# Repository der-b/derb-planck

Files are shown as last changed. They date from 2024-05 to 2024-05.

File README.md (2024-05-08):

# derb-planck

DIY mechanical keyboard which can be connected to several hosts at the same time.
[See blog post for more details.](https://der-b.com/posts/2024-05-08-mechanical-keyboard-derb-planck/)

## PCB

The PCB is designed with KiCad and is located in the subdirectory "PCB".

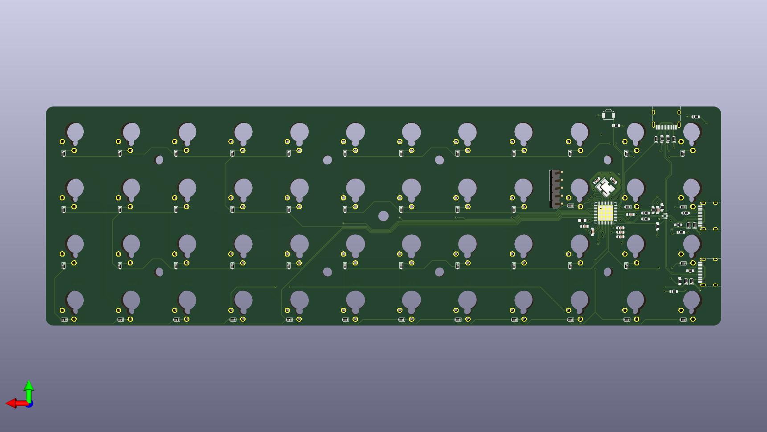
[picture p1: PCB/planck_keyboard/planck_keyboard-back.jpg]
Back

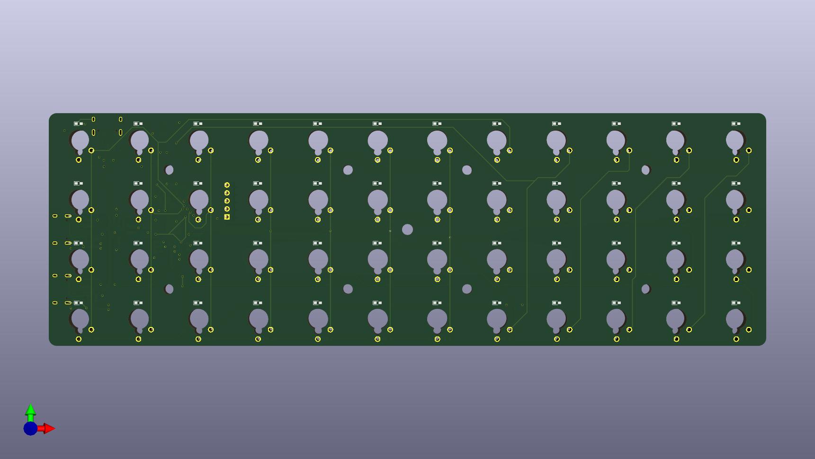
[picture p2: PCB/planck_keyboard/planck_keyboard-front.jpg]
Front


## Case

The Case is designed with FreeCAD and is located in the subdirectory "case".

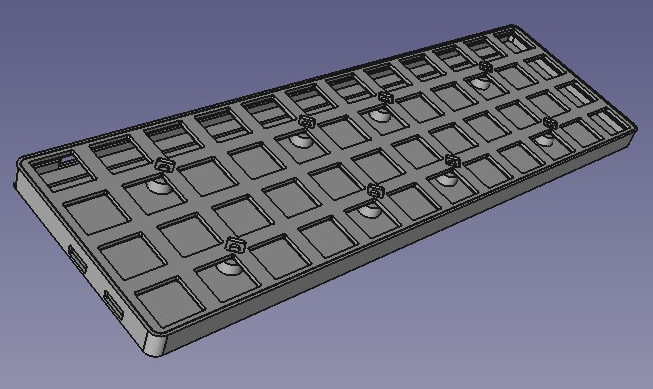
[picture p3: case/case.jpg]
Case


## Firmeware

[This keyboard uses QMK as firmware.](https://github.com/der-b/qmk_firmware/tree/derb_planck/keyboards/handwired/derb_planck)

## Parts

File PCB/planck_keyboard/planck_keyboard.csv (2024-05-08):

# | Reference | Qty | Value | Footprint | DNP
1 | C1, C2, C3, C4 | 4 | 0.1u | Capacitor_SMD:C_0603_1608Metric_Pad1.08x0.95mm_HandSolder
2 | C5 | 1 | 4.7u | Capacitor_SMD:C_0603_1608Metric_Pad1.08x0.95mm_HandSolder
3 | C6 | 1 | 1000p | Capacitor_SMD:C_0603_1608Metric_Pad1.08x0.95mm_HandSolder
4 | C7, C8 | 2 | 22p | Capacitor_SMD:C_0603_1608Metric_Pad1.08x0.95mm_HandSolder
5 | C9 | 1 | 1u | Capacitor_SMD:C_0603_1608Metric_Pad1.08x0.95mm_HandSolder
6 | D0, D1, D2, D3, D4, D5, D6, D7, D8, D9, D10, D11, D12, D13, D14, D15, D16, D17, D18, D19, D20, D21, D22, D23, D24, D25, D26, D27, D28, D29, D30, D31, D32, D33, D34, D35, D36, D37, D38, D39, D40, D41, D42, D43, D44, D45, D46, D47, D48, D49, D50, D51, D52, D53 | 54 | D | Diode_SMD:D_SOD-523
7 | H1, H2, H3, H4, H5, H6, H7, H8 | 8 | MountingHole | MountingHole:MountingHole_3.2mm_M3
8 | HTP0 | 1 | MountingHole | MountingHole:MountingHole_3.5mm
9 | J1, J2, J3 | 3 | USB_C_Receptacle_USB2.0 | Connector_USB:USB_C_Receptacle_HRO_TYPE-C-31-M-12
10 | J4 | 1 | Conn_01x05 | Connector_PinHeader_2.54mm:PinHeader_1x05_P2.54mm_Vertical
11 | R1 | 1 | 100 | Resistor_SMD:R_0603_1608Metric_Pad0.98x0.95mm_HandSolder
12 | R2, R3 | 2 | 22 | Resistor_SMD:R_0603_1608Metric_Pad0.98x0.95mm_HandSolder
13 | R4, R5, R6, R7 | 4 | 10k | Resistor_SMD:R_0603_1608Metric_Pad0.98x0.95mm_HandSolder
14 | R8, R9, R10, R11, R12, R13 | 6 | 5k1 | Resistor_SMD:R_0603_1608Metric_Pad0.98x0.95mm_HandSolder
15 | R14, R15, R16 | 3 | 1k | Resistor_SMD:R_0603_1608Metric_Pad0.98x0.95mm_HandSolder
16 | SW0, SW1, SW2, SW3, SW4, SW5, SW6, SW7, SW8, SW9, SW10, SW11, SW12, SW13, SW14, SW15, SW16, SW17, SW18, SW19, SW20, SW21, SW22, SW23, SW24, SW25, SW26, SW27, SW28, SW29, SW30, SW31, SW32, SW33, SW34, SW35, SW36, SW37, SW38, SW39, SW40, SW41, SW42, SW43, SW44, SW45, SW46, SW47 | 48 | SW_SPST_LED | planck_keyboard:SW_Cherry_MX_LowProfile_1.00u_PCB_V2
17 | SW_RESET1 | 1 | SW_Push | Button_Switch_SMD:SW_SPST_B3U-3000P
18 | U1 | 1 | ATmega32U4RC-M | Package_DFN_QFN:QFN-44-1EP_7x7mm_P0.5mm_EP5.2x5.2mm
19 | U2 | 1 | FSUSB63 | planck_keyboard:FSUSB63
20 | Y1 | 1 | ECS-160-9-33B-CKM-TR3 | Crystal:Crystal_SMD_3225-4Pin_3.2x2.5mm_HandSoldering

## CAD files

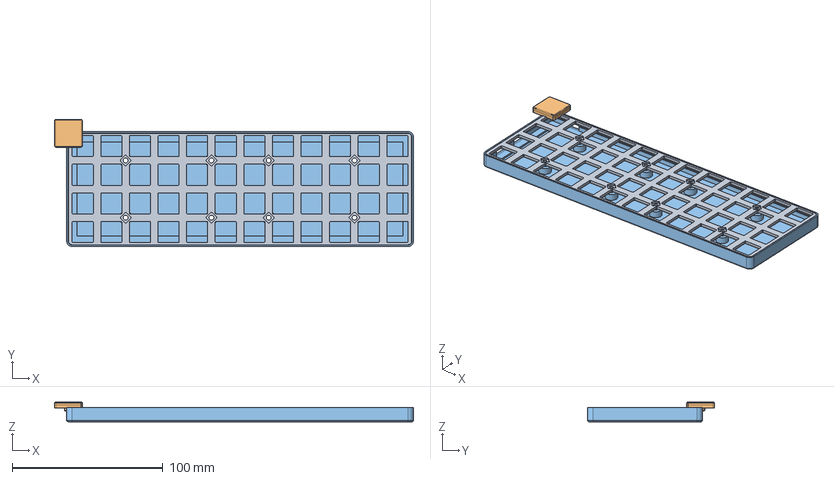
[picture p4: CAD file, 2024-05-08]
case/Case.FCStd
238.5 x 84.5 x 13.0 mm
FacePlate
KeyCap
Case

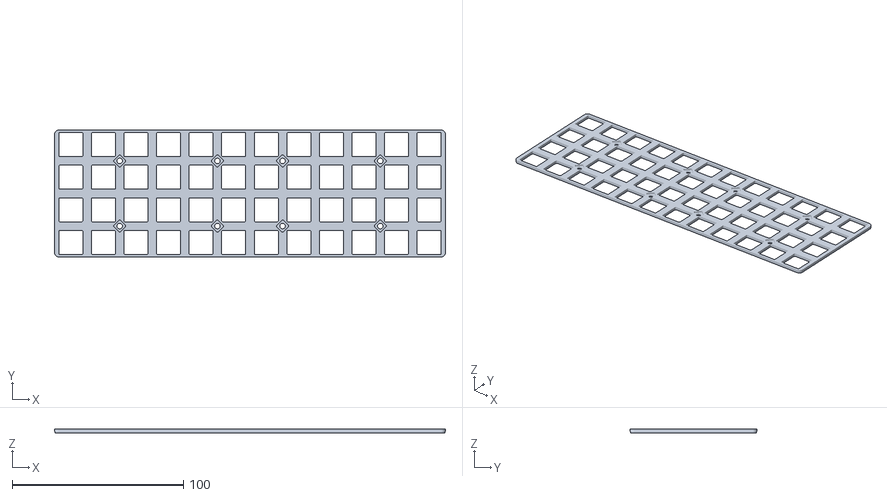
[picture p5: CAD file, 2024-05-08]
case/FacePlate.stl
228.0 x 74.0 x 2.20

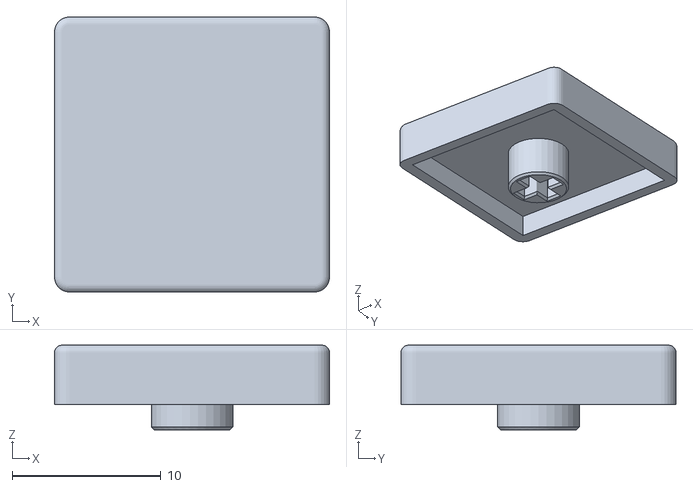
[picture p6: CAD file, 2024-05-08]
case/KeyCap.stl
18.5 x 18.5 x 5.70

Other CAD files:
case/Case.stl

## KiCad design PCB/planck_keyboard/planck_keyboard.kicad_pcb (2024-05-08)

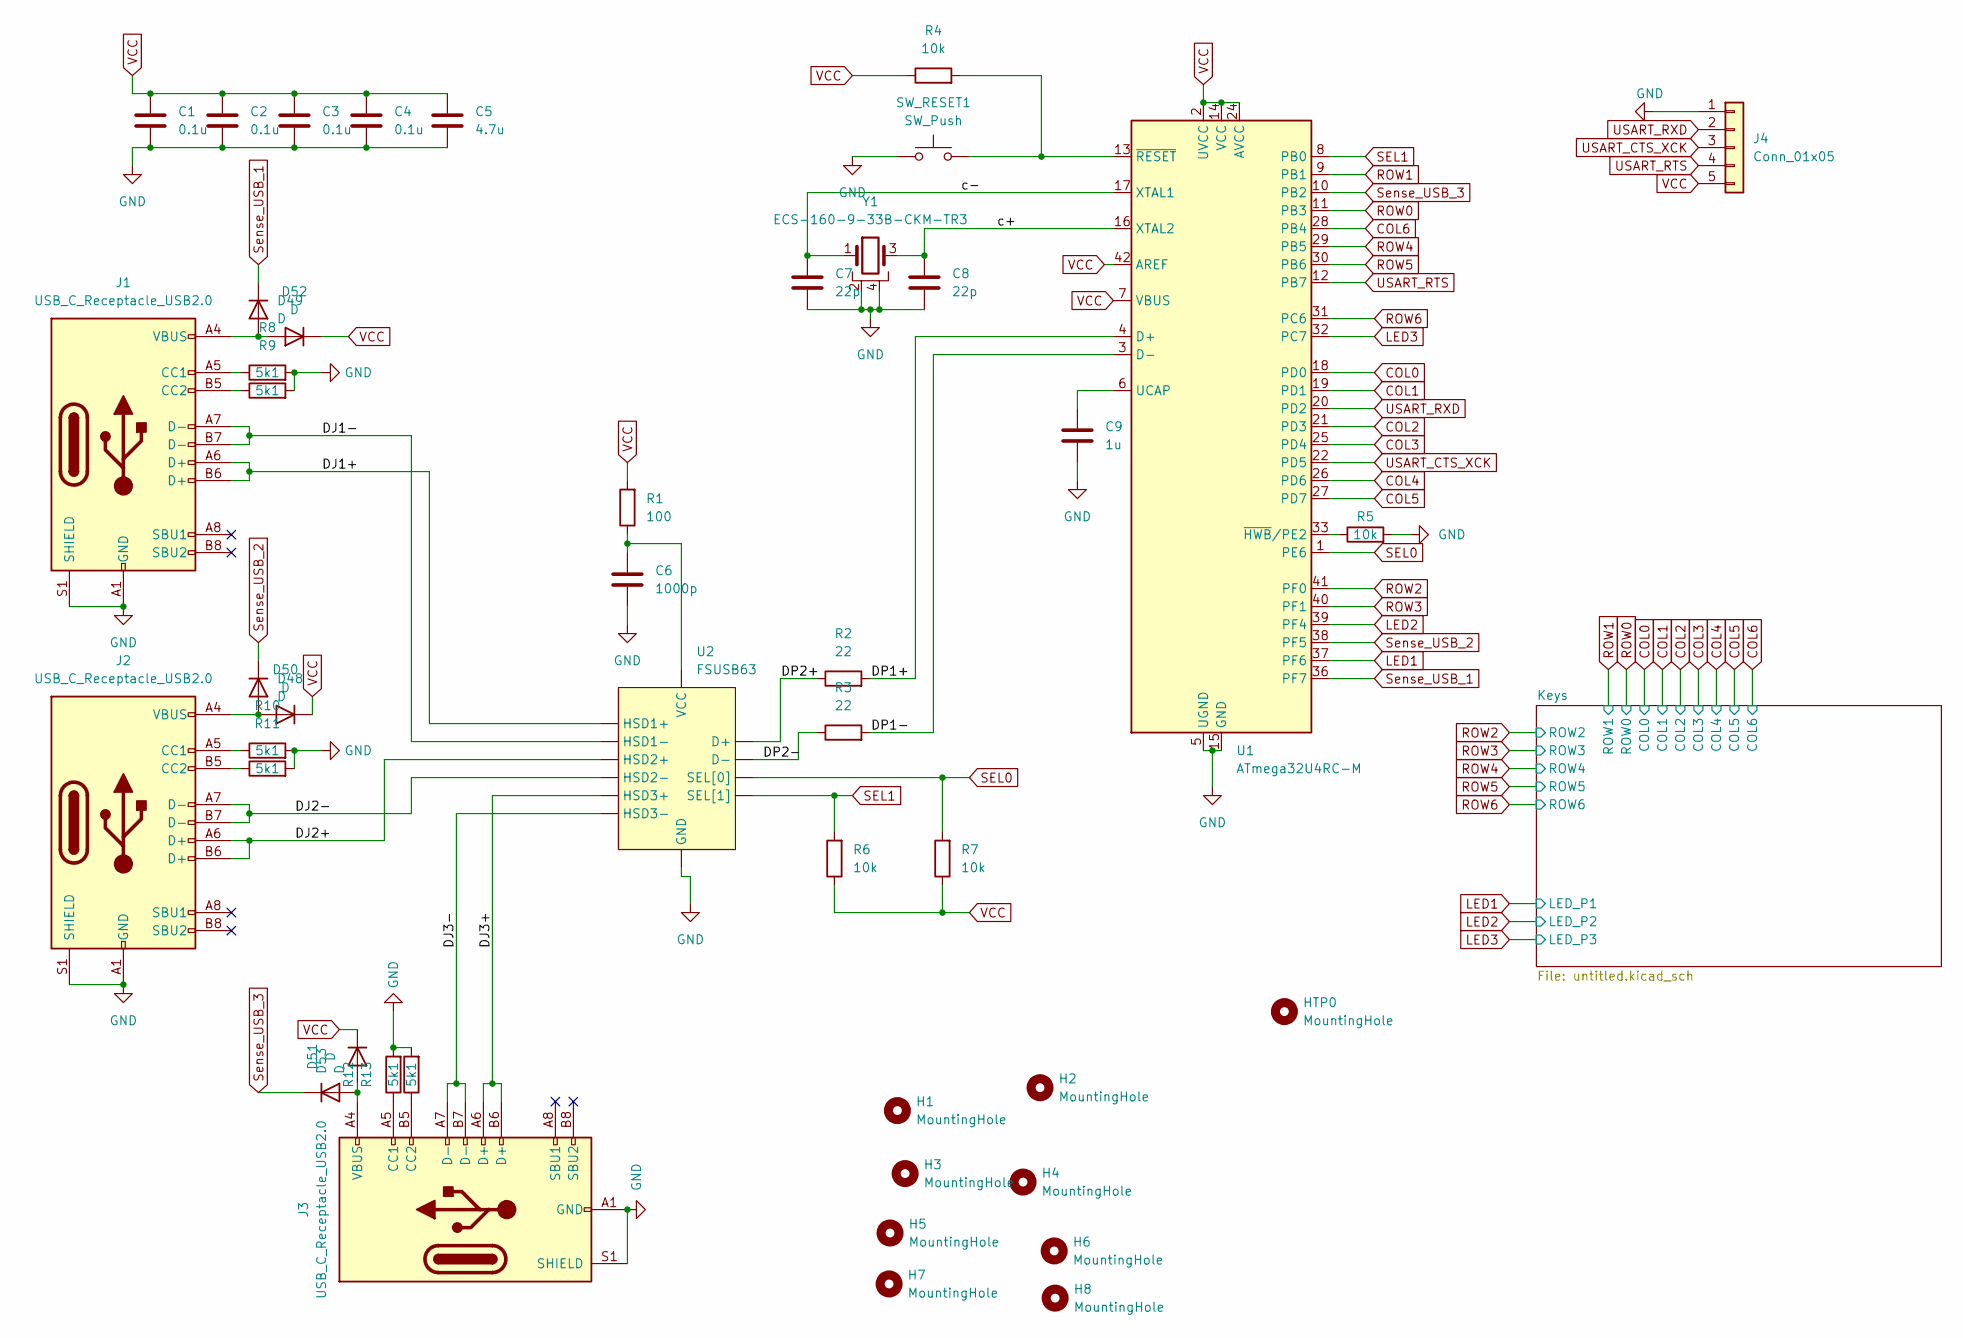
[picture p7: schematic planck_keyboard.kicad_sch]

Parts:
C1, C2, C3, C4: 0.1u; C_0603_1608Metric_Pad1.08x0.95mm_HandSolder
C5: 4.7u; C_0603_1608Metric_Pad1.08x0.95mm_HandSolder
C6: 1000p; C_0603_1608Metric_Pad1.08x0.95mm_HandSolder
C7, C8: 22p; C_0603_1608Metric_Pad1.08x0.95mm_HandSolder
C9: 1u; C_0603_1608Metric_Pad1.08x0.95mm_HandSolder
D48, D49, D50, D51, D52, D53: D; D_SOD-523
H1, H2, H3, H4, H5, H6, H7, H8: MountingHole; MountingHole_3.2mm_M3
HTP0: MountingHole; MountingHole_3.5mm
J1, J2, J3: USB_C_Receptacle_USB2.0; USB_C_Receptacle_HRO_TYPE-C-31-M-12
J4: Conn_01x05; PinHeader_1x05_P2.54mm_Vertical
R1: 100; R_0603_1608Metric_Pad0.98x0.95mm_HandSolder
R2, R3: 22; R_0603_1608Metric_Pad0.98x0.95mm_HandSolder
R4, R5, R6, R7: 10k; R_0603_1608Metric_Pad0.98x0.95mm_HandSolder
R8, R9, R10, R11, R12, R13: 5k1; R_0603_1608Metric_Pad0.98x0.95mm_HandSolder
SW_RESET1: SW_Push; SW_SPST_B3U-3000P
U1: ATmega32U4RC-M; QFN-44-1EP_7x7mm_P0.5mm_EP5.2x5.2mm
U2: FSUSB63
Y1: ECS-160-9-33B-CKM-TR3; Crystal_SMD_3225-4Pin_3.2x2.5mm_HandSoldering

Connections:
/DJ1+: J1.A6 (D+), J1.B6 (D+), U2.6 (HSD1+)
/DJ1-: J1.A7 (D-), J1.B7 (D-), U2.5 (HSD1-)
/DJ2+: J2.A6 (D+), J2.B6 (D+), U2.8 (HSD2+)
/DJ2-: J2.A7 (D-), J2.B7 (D-), U2.7 (HSD2-)
/DJ3+: J3.A6 (D+), J3.B6 (D+), U2.10 (HSD3+)
/DJ3-: J3.A7 (D-), J3.B7 (D-), U2.9 (HSD3-)
/DP1+: R2.2, U1.4 (D+)
/DP1-: R3.2, U1.3 (D-)
/DP2+: R2.1, U2.1 (D+)
/DP2-: R3.1, U2.2 (D-)
/c+: C8.1, U1.16 (XTAL2), Y1.3
/c-: C7.1, U1.17 (XTAL1), Y1.1
COL0: U1.18 (PD0); also elsewhere on the board
COL1: U1.19 (PD1); also elsewhere on the board
COL2: U1.21 (PD3); also elsewhere on the board
COL3: U1.25 (PD4); also elsewhere on the board
COL4: U1.26 (PD6); also elsewhere on the board
COL5: U1.27 (PD7); also elsewhere on the board
COL6: U1.28 (PB4); also elsewhere on the board
LED1: U1.37 (PF6); also elsewhere on the board
LED2: U1.39 (PF4); also elsewhere on the board
LED3: U1.32 (PC7); also elsewhere on the board
unnamed: D48.2 (A), D50.2 (A), J2.A4 (VBUS), J2.A9 (VBUS), J2.B4 (VBUS), J2.B9 (VBUS)
unnamed: D49.2 (A), D52.2 (A), J1.A4 (VBUS), J1.A9 (VBUS), J1.B4 (VBUS), J1.B9 (VBUS)
unnamed: D51.2 (A), D53.2 (A), J3.A4 (VBUS), J3.A9 (VBUS), J3.B4 (VBUS), J3.B9 (VBUS)
unnamed: J1.A5 (CC1), R8.1
unnamed: J1.B5 (CC2), R9.1
unnamed: J2.A5 (CC1), R10.1
unnamed: J2.B5 (CC2), R11.1
unnamed: J3.A5 (CC1), R12.1
unnamed: J3.B5 (CC2), R13.1
unnamed: C9.1, U1.6 (UCAP)
unnamed: R5.1, U1.33 (~HWB/PE2)
unnamed: R4.2, SW_RESET1.2, U1.13 (~RESET)
unnamed: C6.1, R1.1, U2.12 (VCC)
ROW0: U1.11 (PB3); also elsewhere on the board
ROW1: U1.9 (PB1); also elsewhere on the board
ROW2: U1.41 (PF0); also elsewhere on the board
ROW3: U1.40 (PF1); also elsewhere on the board
ROW4: U1.29 (PB5); also elsewhere on the board
ROW5: U1.30 (PB6); also elsewhere on the board
ROW6: U1.31 (PC6); also elsewhere on the board
SEL0: R7.2, U1.1 (PE6), U2.4 (SEL[0])
SEL1: R6.2, U1.8 (PB0), U2.11 (SEL[1])
Sense_USB_1: D49.1 (K), U1.36 (PF7)
Sense_USB_2: D48.1 (K), U1.38 (PF5)
Sense_USB_3: D53.1 (K), U1.10 (PB2)
USART_CTS_XCK: J4.3, U1.22 (PD5)
USART_RTS: J4.4, U1.12 (PB7)
USART_RXD: J4.2, U1.20 (PD2)
VCC: C1.1, C2.1, C3.1, C4.1, C5.1, D50.1 (K), D51.1 (K), D52.1 (K), J4.5, R1.2, R4.1, R6.1, R7.1, U1.2 (UVCC), U1.7 (VBUS), U1.14 (VCC), U1.24 (AVCC), U1.34 (VCC), U1.42 (AREF), U1.44 (AVCC)

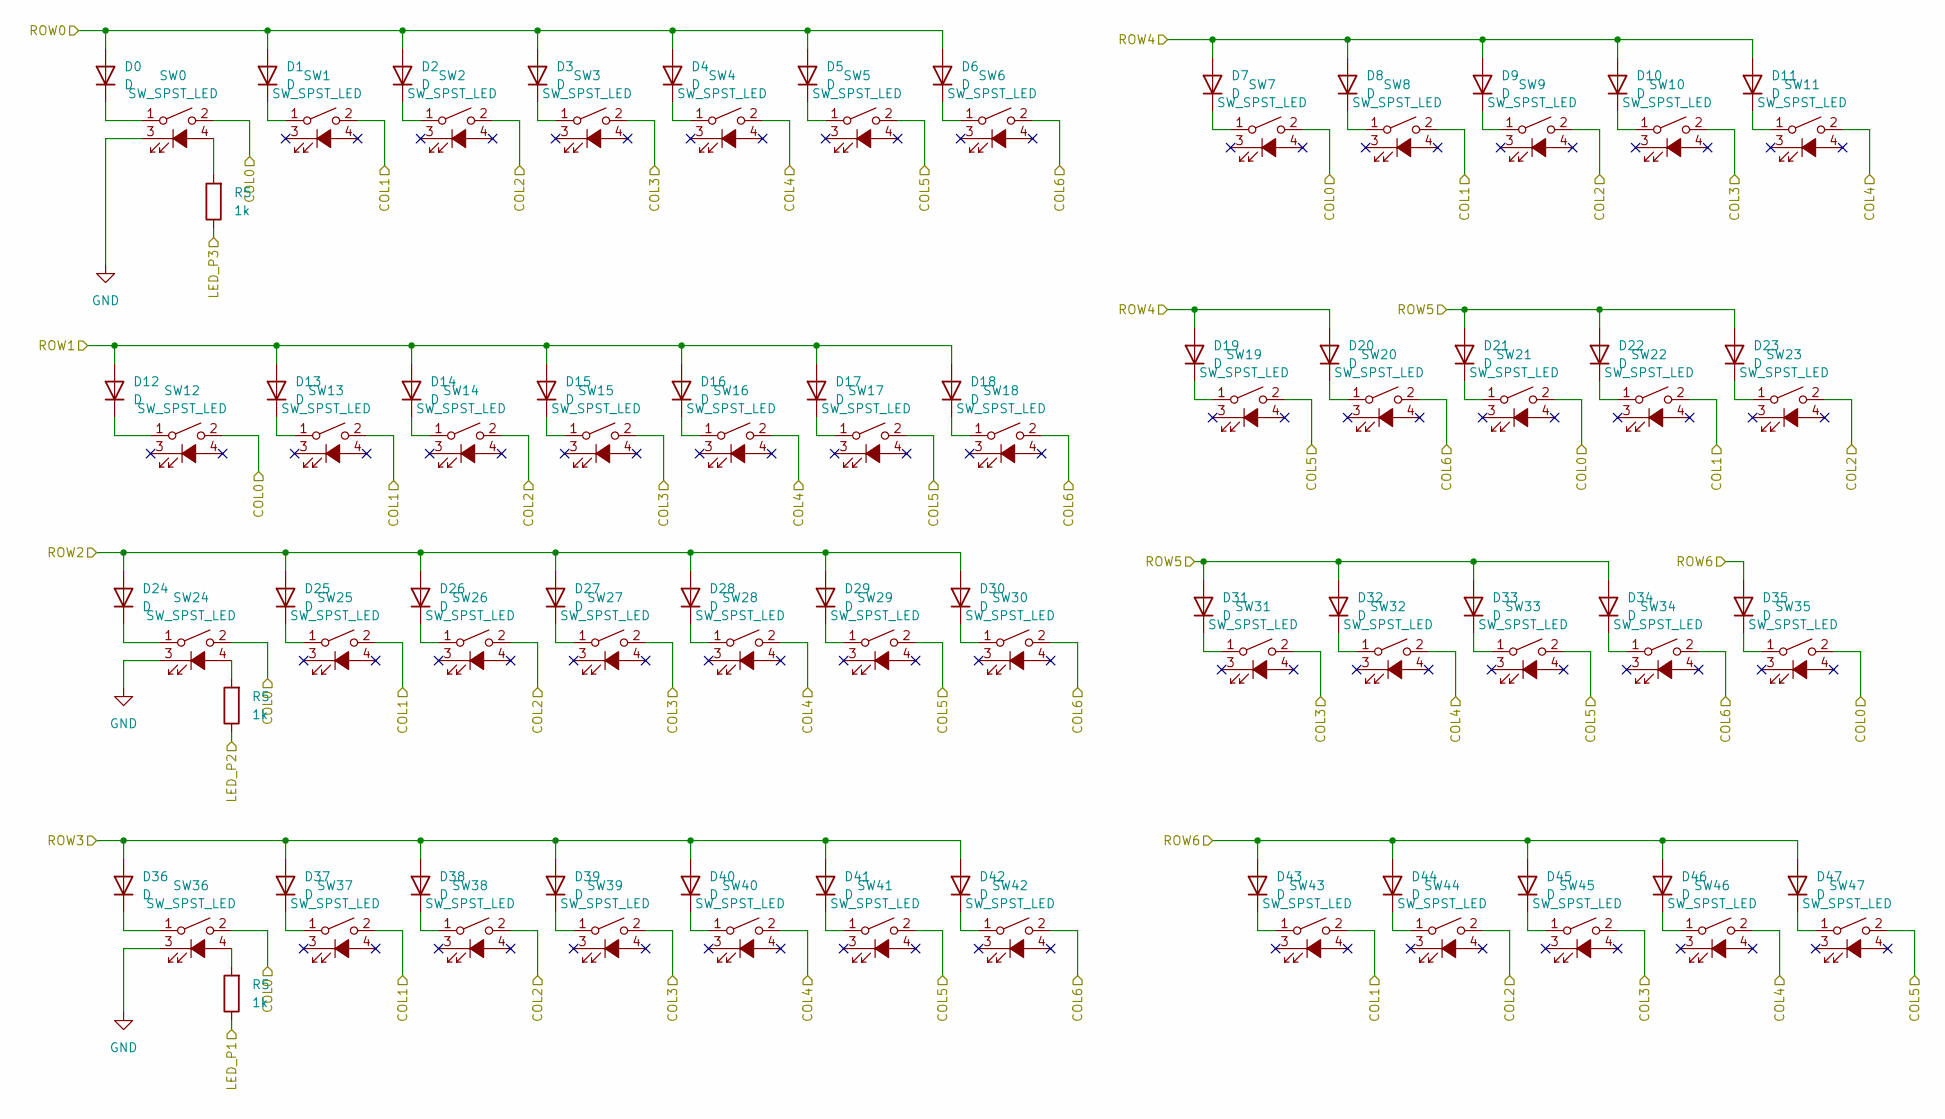
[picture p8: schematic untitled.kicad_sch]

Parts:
D0, D1, D2, D3, D4, D5, D6, D7, D8, D9, D10, D11, D12, D13, D14, D15, D16, D17, D18, D19, D20, D21, D22, D23, D24, D25, D26, D27, D28, D29, D30, D31, D32, D33, D34, D35, D36, D37, D38, D39, D40, D41, D42, D43, D44, D45, D46, D47: D; D_SOD-523
R5: 1k; R_0603_1608Metric_Pad0.98x0.95mm_HandSolder
SW0, SW1, SW2, SW3, SW4, SW5, SW6, SW7, SW8, SW9, SW10, SW11, SW12, SW13, SW14, SW15, SW16, SW17, SW18, SW19, SW20, SW21, SW22, SW23, SW24, SW25, SW26, SW27, SW28, SW29, SW30, SW31, SW32, SW33, SW34, SW35, SW36, SW37, SW38, SW39, SW40, SW41, SW42, SW43, SW44, SW45, SW46, SW47: SW_SPST_LED; SW_Cherry_MX_LowProfile_1.00u_PCB_V2

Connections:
COL0: SW0.2, SW7.2, SW12.2, SW21.2, SW24.2, SW35.2, SW36.2; also elsewhere on the board
COL1: SW1.2, SW8.2, SW13.2, SW22.2, SW25.2, SW37.2, SW43.2; also elsewhere on the board
COL2: SW2.2, SW9.2, SW14.2, SW23.2, SW26.2, SW38.2, SW44.2; also elsewhere on the board
COL3: SW3.2, SW10.2, SW15.2, SW27.2, SW31.2, SW39.2, SW45.2; also elsewhere on the board
COL4: SW4.2, SW11.2, SW16.2, SW28.2, SW32.2, SW40.2, SW46.2; also elsewhere on the board
COL5: SW5.2, SW17.2, SW19.2, SW29.2, SW33.2, SW41.2, SW47.2; also elsewhere on the board
COL6: SW6.2, SW18.2, SW20.2, SW30.2, SW34.2, SW42.2; also elsewhere on the board
unnamed: D0.1 (K), SW0.1
unnamed: D1.1 (K), SW1.1
unnamed: D2.1 (K), SW2.1
unnamed: D3.1 (K), SW3.1
unnamed: D4.1 (K), SW4.1
unnamed: D5.1 (K), SW5.1
unnamed: D6.1 (K), SW6.1
unnamed: D7.1 (K), SW7.1
unnamed: D8.1 (K), SW8.1
unnamed: D9.1 (K), SW9.1
unnamed: D10.1 (K), SW10.1
unnamed: D11.1 (K), SW11.1
unnamed: D12.1 (K), SW12.1
unnamed: D13.1 (K), SW13.1
unnamed: D14.1 (K), SW14.1
unnamed: D15.1 (K), SW15.1
unnamed: D16.1 (K), SW16.1
unnamed: D17.1 (K), SW17.1
unnamed: D18.1 (K), SW18.1
unnamed: D19.1 (K), SW19.1
unnamed: D20.1 (K), SW20.1
unnamed: D21.1 (K), SW21.1
unnamed: D22.1 (K), SW22.1
unnamed: D23.1 (K), SW23.1
unnamed: D24.1 (K), SW24.1
unnamed: D25.1 (K), SW25.1
unnamed: D26.1 (K), SW26.1
unnamed: D27.1 (K), SW27.1
unnamed: D28.1 (K), SW28.1
unnamed: D29.1 (K), SW29.1
unnamed: D30.1 (K), SW30.1
unnamed: D31.1 (K), SW31.1
unnamed: D32.1 (K), SW32.1
unnamed: D33.1 (K), SW33.1
unnamed: D34.1 (K), SW34.1
unnamed: D35.1 (K), SW35.1
unnamed: D36.1 (K), SW36.1
unnamed: D37.1 (K), SW37.1
unnamed: D38.1 (K), SW38.1
unnamed: D39.1 (K), SW39.1
unnamed: D40.1 (K), SW40.1
unnamed: D41.1 (K), SW41.1
unnamed: D42.1 (K), SW42.1
unnamed: D43.1 (K), SW43.1
unnamed: D44.1 (K), SW44.1
unnamed: D45.1 (K), SW45.1
unnamed: D46.1 (K), SW46.1
unnamed: D47.1 (K), SW47.1
unnamed 80: R5.1; also elsewhere on the board
ROW0: D0.2 (A), D1.2 (A), D2.2 (A), D3.2 (A), D4.2 (A), D5.2 (A), D6.2 (A); also elsewhere on the board
ROW1: D12.2 (A), D13.2 (A), D14.2 (A), D15.2 (A), D16.2 (A), D17.2 (A), D18.2 (A); also elsewhere on the board
ROW2: D24.2 (A), D25.2 (A), D26.2 (A), D27.2 (A), D28.2 (A), D29.2 (A), D30.2 (A); also elsewhere on the board
ROW3: D36.2 (A), D37.2 (A), D38.2 (A), D39.2 (A), D40.2 (A), D41.2 (A), D42.2 (A); also elsewhere on the board
ROW4: D7.2 (A), D8.2 (A), D9.2 (A), D10.2 (A), D11.2 (A), D19.2 (A), D20.2 (A); also elsewhere on the board
ROW5: D21.2 (A), D22.2 (A), D23.2 (A), D31.2 (A), D32.2 (A), D33.2 (A), D34.2 (A); also elsewhere on the board
ROW6: D35.2 (A), D43.2 (A), D44.2 (A), D45.2 (A), D46.2 (A), D47.2 (A); also elsewhere on the board

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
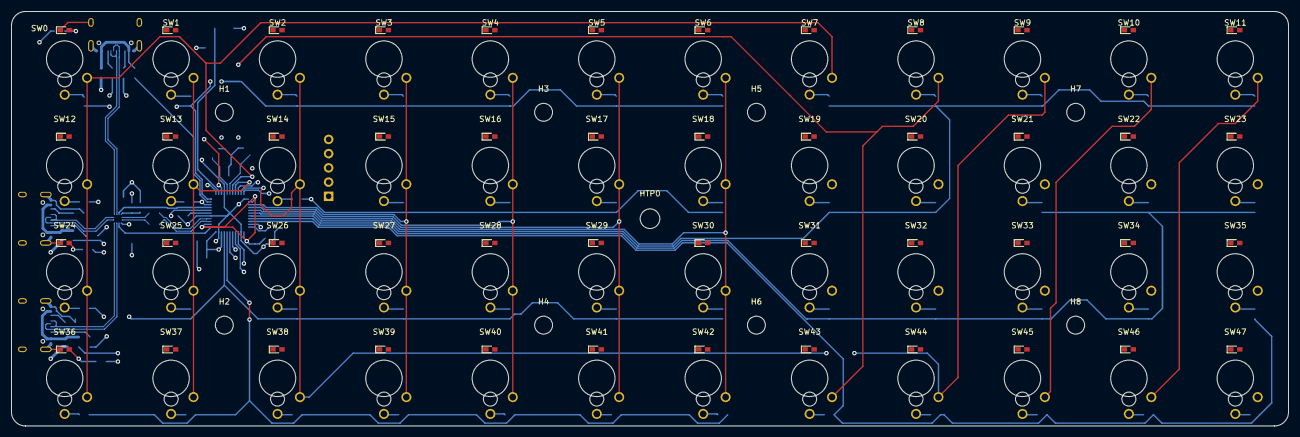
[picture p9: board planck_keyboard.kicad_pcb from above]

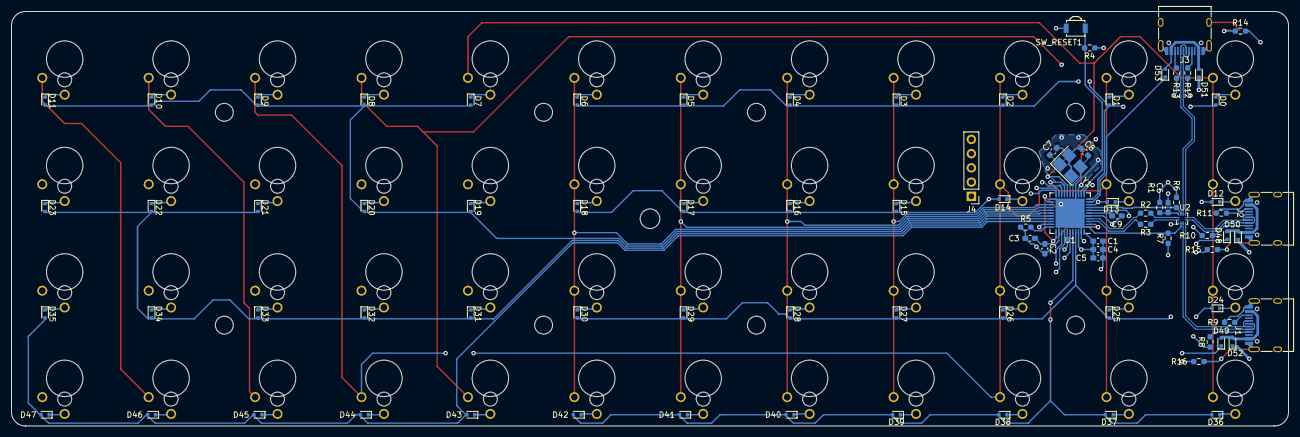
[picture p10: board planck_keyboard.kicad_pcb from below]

Board: 4 copper layers, 228.0 x 74.0 mm, 144 parts (87 on the bottom side), 103 nets.

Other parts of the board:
R14, R15, R16: 1k; R_0603_1608Metric_Pad0.98x0.95mm_HandSolder

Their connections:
LED1: R16.1; also elsewhere on the board
LED2: R15.1; also elsewhere on the board
LED3: R14.1; also elsewhere on the board
